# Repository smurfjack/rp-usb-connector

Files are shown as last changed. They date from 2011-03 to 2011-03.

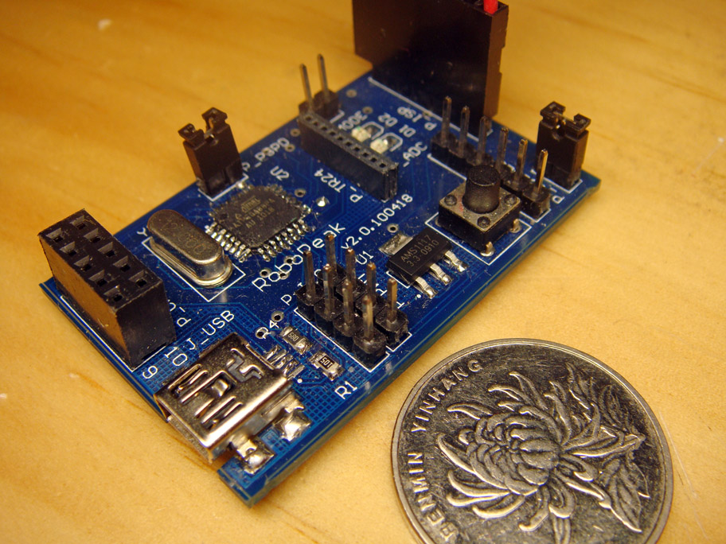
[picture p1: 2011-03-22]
hardware/referece_layout/rp_usb_connector_002.jpg

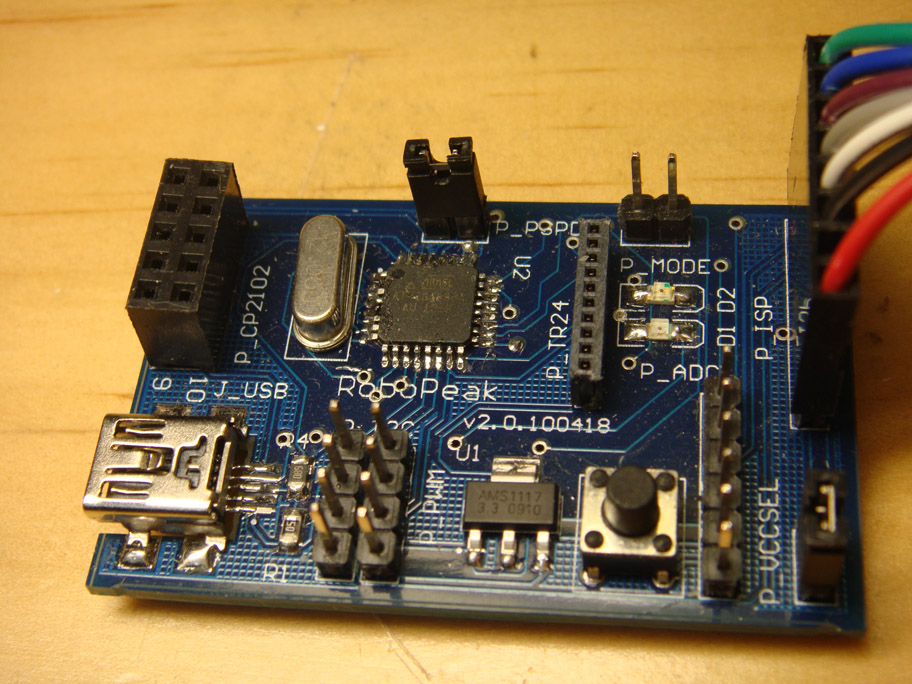
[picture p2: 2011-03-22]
hardware/referece_layout/rp_usb_connector_003.jpg

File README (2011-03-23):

INTRODUCTION:
--------------------------------

RoboPeak USB Connector is a driverless USB ISP programmer for AVR/C51 MCU. It is developed by RoboPeak team (www.RoboPeak.com).

RoboPeak USB Connector is based on the work of AVR-Doper project (http://www.obdev.at/products/vusb/avrdoper.html), which is a STK500 compatible In-System Programmer (ISP) and High Voltage Serial Programmer (HVSP). 

The USB connectivity is achieved using the v-usb lib (a software-only implementation of a low-speed USB device for Atmel's AVR microcontrollers). We only use a simple AVR MCU in the circuit. 

The RoboPeak USB Connector can be considered as a simplified version of AVR-Doper, besides, the firmware has been written using Arduino-Lite firmware libarary and the building system. 

Supported Operating Systems:
---------------------------------
In theory, any OS with build-in HID usb drivers is supported. 
As the PC-side client (avrdude.exe) can work on the following systems, RoboPeak USB Connector should work for these systems as well:

<> Linux with libusb
<> Windows from the version WinXP
<> MacOS

We had verified the following Windows Versions:
<> Windows XP
<> Windows Vista, both 32bit and 64 bit versions
<> Windows 7, both 32bit and 64 bit versions

How to compile the firmware?
---------------------------------

The RoboPeak USB Connector requires Arduino-Lite to build the hex file, please refer to the document under firmware folder (README.txt) for details.

How to make the hardware?
---------------------------------

The hardware folder contains the schematic of RoboPeak USB Connector. The PCB layout file will be released soon, you may refer to the referece_layout/.

Besides, The AVR-Doper should support our firmware as well.

How to program a new-made RoboPeak USB Connector?
---------------------------------
You may use the make burnall command to program a new-made RoboPeak USB Connector. This command will burn the firmware hex into the AVR chip along with the BootloaderHID bootloader. The target AVR chip fuse setting will be configed automatically by this command.

You can also program the RoboPeak USB Connector manually, the fuse setting are:

// for Atmega88 only
LFUSE=CE
HFUSE=DD
EFUSE=00

You will need to burn the BootloaderHID firmware as well, the hex file can be found in the Arduino-Lite project ( <Arduino-Lite/src/bootloaders/hidbootloader/pre-compiled/mega88_12M.hex)

How to use it?
---------------------------------
You may refer to the AVR-Doper document for its general usage:
  http://www.obdev.at/products/vusb/avrdoper.html

We recommend you to use RoboPeak USB Connector with Arduino-Lite together, as the Arduino-Lite building system contains the build-in support of RoboPeak USB Connector (AVR-Doper).

You can program the AVR chip simply using the "make burn" command with Arduino-Lite.

You may view the video-chip of the burning progress with Arduino-Lite:
  http://www.tudou.com/programs/view/Den9uh3HTHE/

Self-Program?
---------------------------------
Self-Program is supported by RoboPeak USB Connector. The firmware also contains a driverless USB bootloader called BootloadHID (http://www.obdev.at/products/vusb/bootloadhid.html).

In some circumstance, e.g. you need to update the firmware but you only have one RoboPeak USB Connector, the self-program ability is very helpful.

To use this feature, follow these steps:
<> shortcut the pin ADC0(PC1) and VCC of the Pin P_ADC
<> connect the RoboPeak USB Connector to PC
<> The OS should prompt a device called HIDboot has been connected
<> enter the RoboPeak USB Connector firmware project folder, launch the bash shell, type 
   make usbupload

REFERENCE:
---------------------------------
Project Homepage:       http://code.google.com/p/rp-usb-connector/
Arduino-Lite Homepage:  http://code.google.com/p/arduino-lite/
RoboPeak Team:          http://www.RoboPeak.com
AVR-Doper:              http://www.obdev.at/products/vusb/avrdoper.html

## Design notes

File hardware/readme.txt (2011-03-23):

Please use Altium Designer to view the sch source file.

The PCB layout will be ready soon. You may refer to the image in the referece_layout currently.

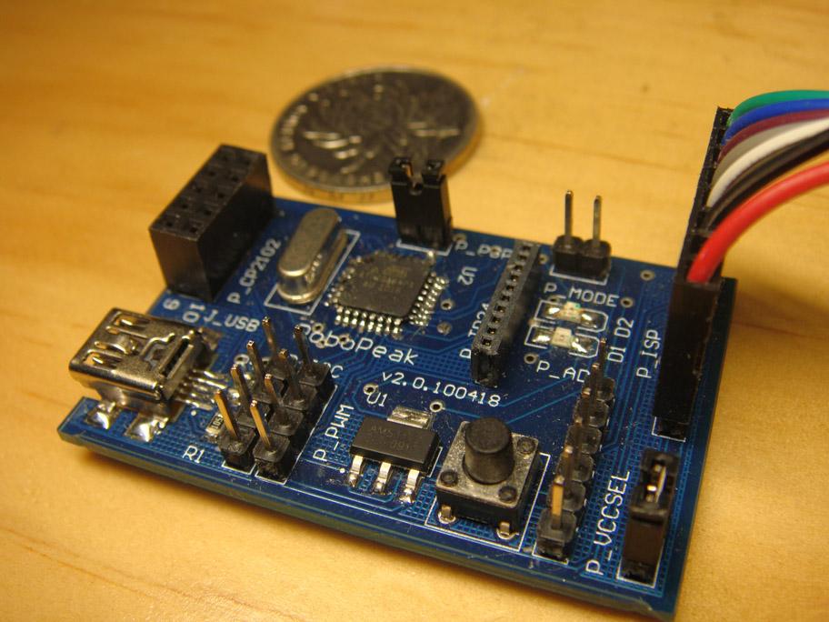
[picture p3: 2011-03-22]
hardware/referece_layout/rp_usb_connector_001.jpg

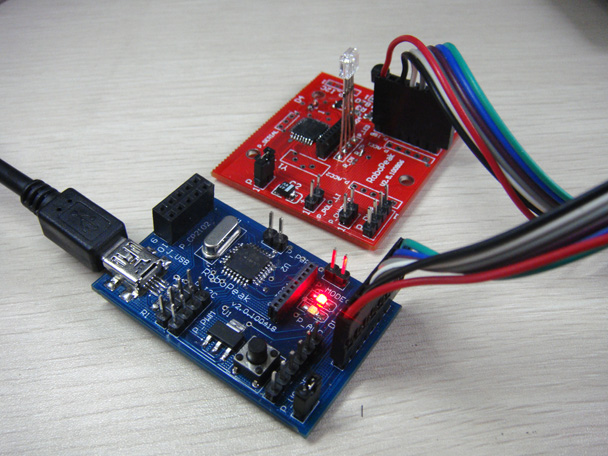
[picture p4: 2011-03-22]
hardware/referece_layout/rp_usb_connector_release_ver.jpg

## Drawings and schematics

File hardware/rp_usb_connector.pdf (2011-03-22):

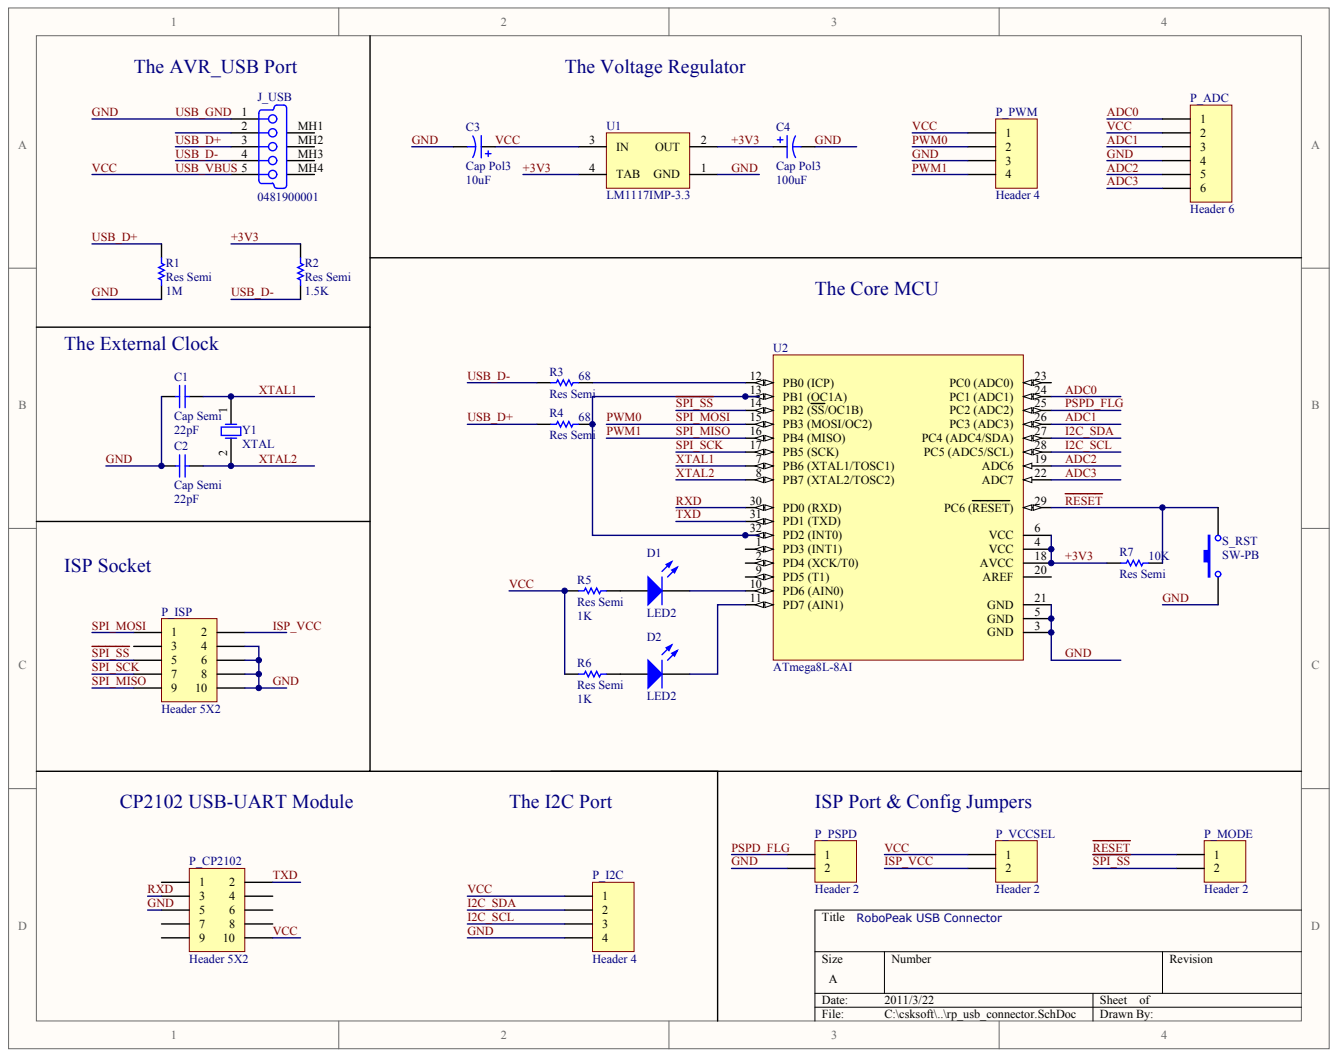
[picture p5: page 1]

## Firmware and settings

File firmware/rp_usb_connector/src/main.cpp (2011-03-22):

/*
 *  RoboPeak Bridge 
 *  By Shikai Chen
 *
 */

/*
   Copyright statements of the reference source:
*/
/* Name: main.c
 * Project: AVR-Doper
 * Author: Christian Starkjohann <cs@obdev.at>
 * Creation Date: 2006-06-21
 * Tabsize: 4
 * Copyright: (c) 2006 by Christian Starkjohann, all rights reserved.
 * License: GNU GPL v2 (see License.txt) or proprietary (CommercialLicense.txt)
 * Revision: $Id: main.c 702 2008-11-26 20:16:54Z cs $
 */

/*
General Description:
This module implements hardware initialization and the USB interface
*/

#include "common.h"

extern "C"{
#include "usbdrv/usbdrv.h"
}

#include "avr-doper/utils.h"
#include "stk500protocol.h"
#include "avr-doper/serial.h"

#include "working_mode.h"

volatile _u8    bridgeWorkingMode;

static void setWorkingType(void)
{
    // retrieve the working mode from the current P_PSPD pin
//	if (DIGITAL_READ(JUMPER_MODE_SEL)) {
		bridgeWorkingMode = MODE_AVR_DOPER;
        LED_TX_ON();
        delay(100);
        LED_TX_OFF();
    
        delay(100);
      
        LED_RX_ON();
        delay(100);
        LED_RX_OFF();
//	} else {
//		bridgeWorkingMode = MODE_RF_AP;
//		init_rf_dev();
//	}
}

void setup(void)
{
    init();
    PORTB = 0;
    DDRB = 0;
    PORTC = 0;
    DDRC = 0;
    PORTD = 0;
    DDRD = 0;

    LED_INIT();

    DIGITAL_WRITE(JUMPER_MODE_SEL, HIGH);
    
    cbi(USB_PORT, USB_PORT_P);
    cbi(USB_PORT, USB_PORT_N);
    cbi(USB_DDR, USB_PORT_P);
    cbi(USB_DDR, USB_PORT_N);



    usbDeviceDisconnect();  /* enforce re-enumeration, do this while interrupts are disabled! */
}

static inline void postsetup(void)
{
    // Connect the USB
	wdt_reset();
	delay(128);
	delay(128);
	usbDeviceConnect();
}


int main(void)
{
    wdt_enable(WDTO_2S);

#if ENABLE_DEBUG_INTERFACE
    serialInit();
#endif

    setup();
    setWorkingType();
    postsetup();
    usbInit();
    sei();
    for(;;){    /* main event loop */
        wdt_reset();
        usbPoll();
        stkPoll();
    }
    
    return 0;
}

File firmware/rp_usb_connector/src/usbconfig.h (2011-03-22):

/*
  RoboPeak Project
  Common USB Conf header for Sunjar Bridge / USB-Doper / USB-CDC Usage

  Initial Version by CSK
*/


/* Name: usbconfig.h
 * Project: AVR-Doper
 * Author: Christian Starkjohann
 * Creation Date: 2006-07-18
 * Tabsize: 4
 * Copyright: (c) 2006 by OBJECTIVE DEVELOPMENT Software GmbH
 * License: GNU GPL v2 (see License.txt) or proprietary (CommercialLicense.txt)
 * This Revision: $Id: usbconfig.h 566 2008-04-26 14:21:47Z cs $
 */

#ifndef __usbconfig_h_included__
#define __usbconfig_h_included__

#include "conf.h"   /* for ENABLE_HID_INTERFACE, pins for USB */


/*
General Description:
USB driver configuration for RP-Bridge

Please note that the usbdrv contains a usbconfig-prototype.h file now. We
recommend that you use that file as a template because it will always list
the newest features and options.
*/

/* ---------------------------- Hardware Config ---------------------------- */


#define USB_CFG_IOPORTNAME      USB_PORT_NAME
/* This is the port where the USB bus is connected. When you configure it to
 * "B", the registers PORTB, PINB and DDRB will be used.
 */
#define USB_CFG_DMINUS_BIT      USB_PORT_N
/* This is the bit number in USB_CFG_IOPORT where the USB D- line is connected.
 * This may be any bit in the port.
 */
#define USB_CFG_DPLUS_BIT       USB_PORT_P
/* This is the bit number in USB_CFG_IOPORT where the USB D+ line is connected.
 * This may be any bit in the port. Please note that D+ must also be connected
 * to interrupt pin INT0!
 */
#define USB_CFG_CLOCK_KHZ       (F_CPU/1000)
/* Clock rate of the AVR in MHz. Legal values are 12000, 16000 or 16500.
 * The 16.5 MHz version of the code requires no crystal, it tolerates +/- 1%
 * deviation from the nominal frequency. All other rates require a precision
 * of 2000 ppm and thus a crystal!
 * Default if not specified: 12 MHz
 */

/* ----------------------- Optional Hardware Config ------------------------ */

/* #define USB_CFG_PULLUP_IOPORTNAME   D */
/* If you connect the 1.5k pullup resistor from D- to a port pin instead of
 * V+, you can connect and disconnect the device from firmware by calling
 * the macros usbDeviceConnect() and usbDeviceDisconnect() (see usbdrv.h).
 * This constant defines the port on which the pullup resistor is connected.
 */
/* #define USB_CFG_PULLUP_BIT          4 */
/* This constant defines the bit number in USB_CFG_PULLUP_IOPORT (defined
 * above) where the 1.5k pullup resistor is connected. See description
 * above for details.
 */

/* --------------------------- Functional Range ---------------------------- */
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

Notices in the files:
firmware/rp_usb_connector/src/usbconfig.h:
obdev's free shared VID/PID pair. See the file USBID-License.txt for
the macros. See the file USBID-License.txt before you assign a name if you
